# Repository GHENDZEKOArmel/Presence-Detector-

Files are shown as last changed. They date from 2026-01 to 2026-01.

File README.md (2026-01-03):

# Infrared Presence Detector – Electronic Design (KiCad)

##  Description
This project focuses on the design of an **active infrared presence detector** based on a
**fully analog signal processing chain**.

The system emits a modulated infrared signal, detects the reflection caused by a nearby object
(human presence), and processes the received signal in order to generate a **usable logic output**.

The project was designed and simulated using **KiCad**, with an **academic and educational purpose**,
following a modular architecture inspired by industrial detection systems.

---

##  Operating Principle

1. An **infrared emitting diode (IR LED)** generates a modulated IR signal.
2. A **photodiode receiver** detects the reflected infrared signal.
3. The received current is converted into a voltage (TIA).
4. A **band-pass filter** rejects ambient noise.
5. The signal is **amplified**.
6. A **peak detector** extracts the signal envelope.
7. A **comparator** compares the signal with an adjustable threshold.
8. A **logic output** indicates the detected presence.

### Functional blocks

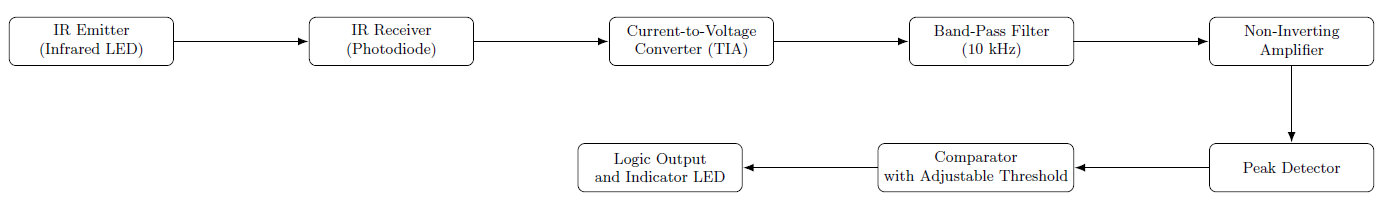
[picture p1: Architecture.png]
System architecture of the presence detector


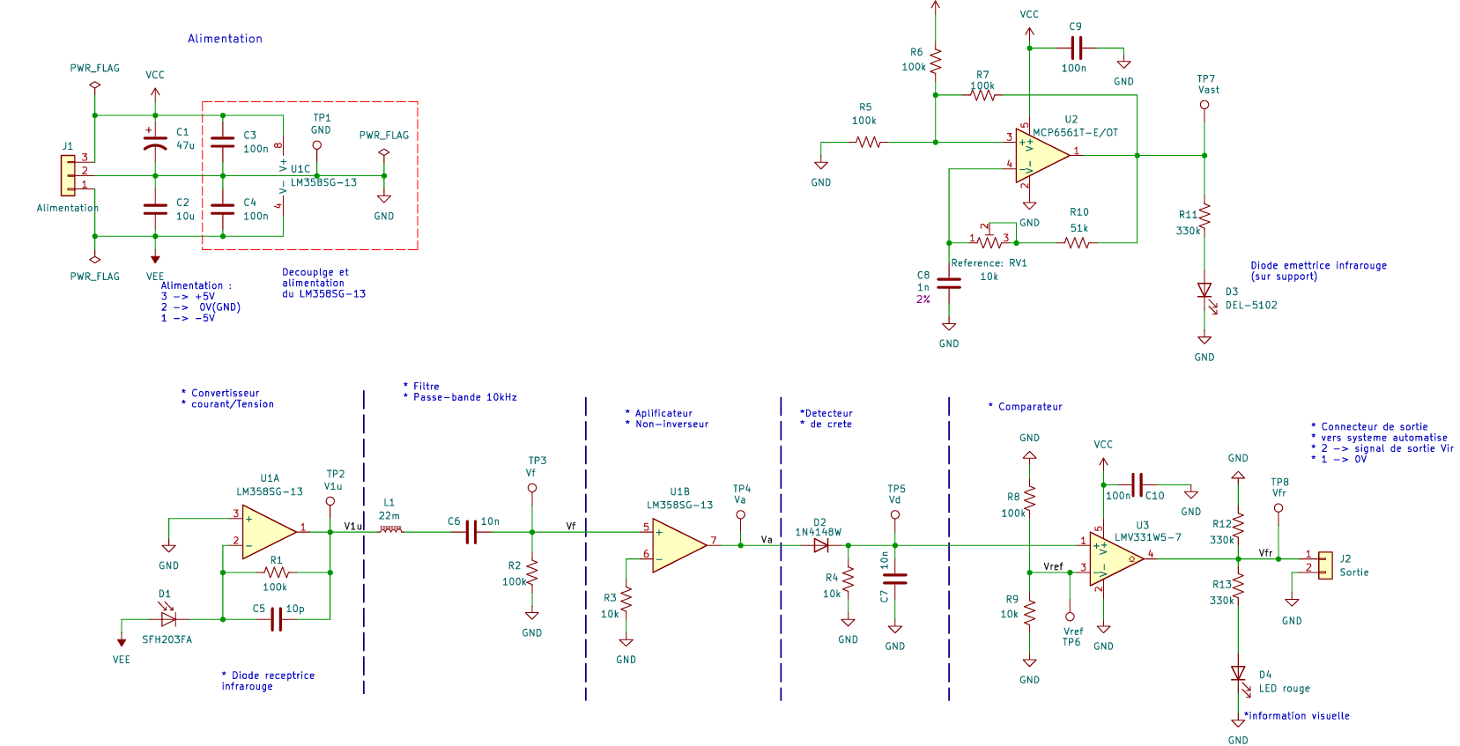
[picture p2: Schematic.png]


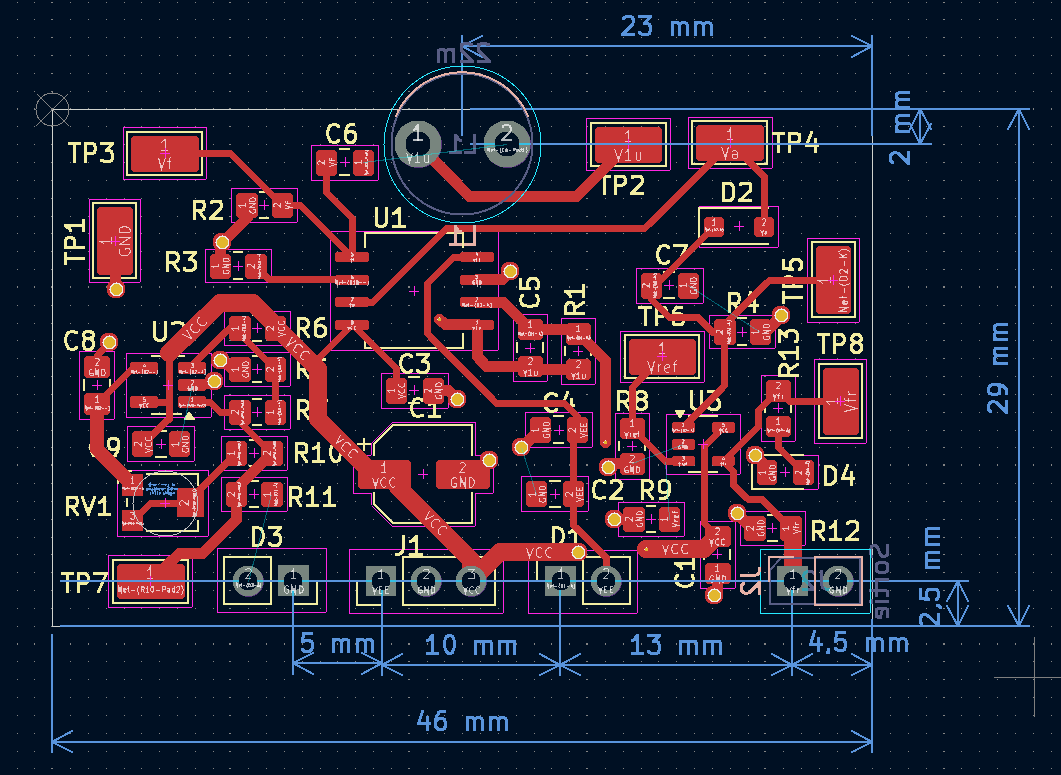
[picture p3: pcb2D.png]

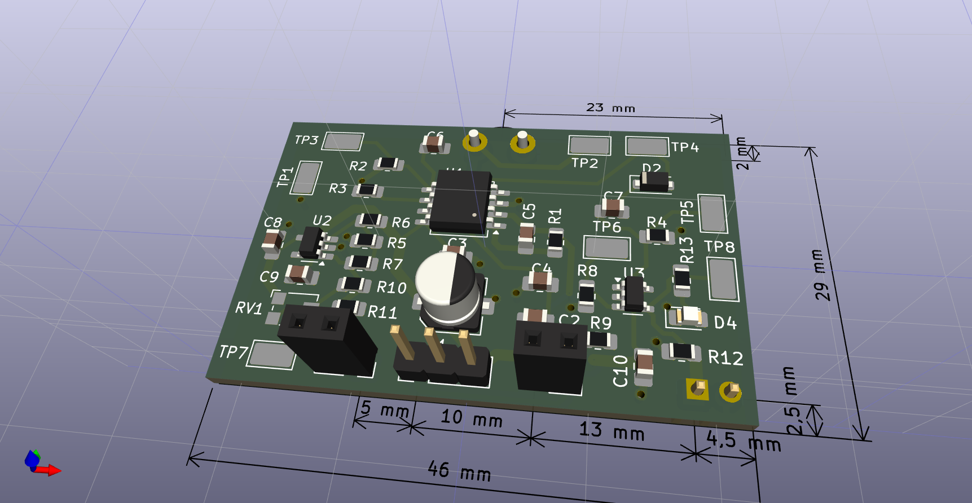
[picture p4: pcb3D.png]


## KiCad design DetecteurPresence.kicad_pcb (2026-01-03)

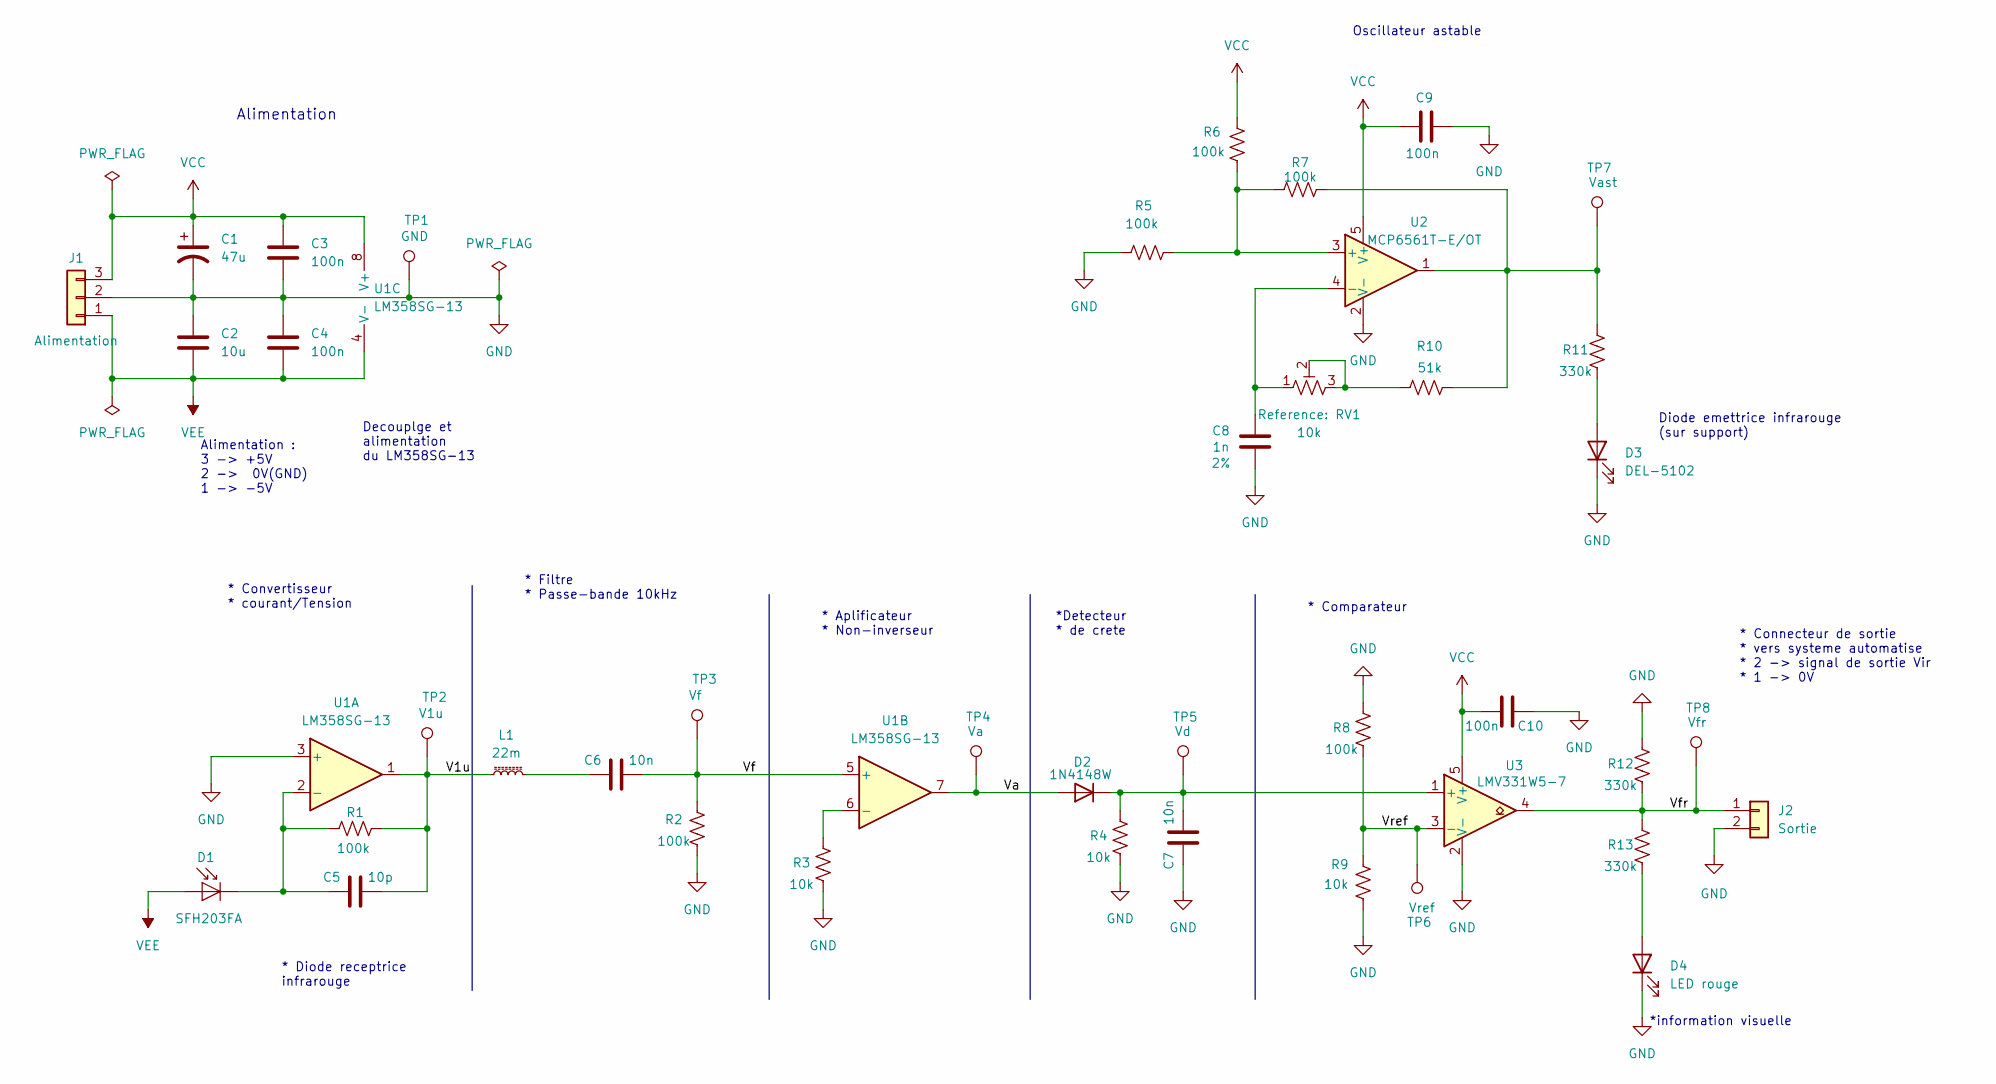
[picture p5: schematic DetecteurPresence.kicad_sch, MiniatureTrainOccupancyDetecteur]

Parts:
C1: 47u; CP_Elec_5x5.4
C2: 10u; C_0805_2012Metric_Pad1.18x1.45mm_HandSolder
C3, C4, C9, C10: 100n; C_0805_2012Metric_Pad1.18x1.45mm_HandSolder
C5: 10p; C_0805_2012Metric_Pad1.18x1.45mm_HandSolder
C6, C7: 10n; C_0805_2012Metric_Pad1.18x1.45mm_HandSolder
C8: 1n; C_0805_2012Metric_Pad1.18x1.45mm_HandSolder; Tolerance 2%
D1: SFH203FA; PinSocket_1x02_P2.54mm_Vertical
D2: 1N4148W; D_SOD-123F
D3: DEL-5102; PinSocket_1x02_P2.54mm_Vertical
D4: LED rouge; LED_0805_2012Metric_Pad1.15x1.40mm_HandSolder
J1: Alimentation; PinHeader_1x03_P2.54mm_Vertical
J2: Sortie; PinHeader_1x02_P2.54mm_Vertical
L1: 22m; L_Radial_D7.8mm_P5.00mm_Fastron_07HCP
R1, R2, R5, R6, R7, R8: 100k; R_0805_2012Metric_Pad1.20x1.40mm_HandSolder
R3, R4, R9: 10k; R_0805_2012Metric_Pad1.20x1.40mm_HandSolder
R10: 51k; R_0805_2012Metric_Pad1.20x1.40mm_HandSolder
R11, R12, R13: 330k; R_0805_2012Metric_Pad1.20x1.40mm_HandSolder
RV1: 10k; Potentiometer_Bourns_TC33X_Vertical
TP1: GND; TestPoint_Keystone_5019_Miniature
TP2: V1u; TestPoint_Keystone_5019_Miniature
TP3: Vf; TestPoint_Keystone_5019_Miniature
TP4: Va; TestPoint_Keystone_5019_Miniature
TP5: Vd; TestPoint_Keystone_5019_Miniature
TP6: Vref; TestPoint_Keystone_5019_Miniature
TP7: Vast; TestPoint_Keystone_5019_Miniature
TP8: Vfr; TestPoint_Keystone_5019_Miniature
U1: LM358SG-13; SOIC-8_5.3x6.2mm_P1.27mm
U2: MCP6561T-E/OT; SOT-23-5_HandSoldering
U3: LMV331W5-7; SOT-23-5

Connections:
/V1u: C5.2, L1.1, R1.2, TP2.1, U1.1
/Va: D2.2 (A), TP4.1, U1.7
/Vf: C6.2, R2.2, TP3.1, U1.5 (+)
/Vfr: J2.1, R12.1, R13.2, TP8.1, U3.4
/Vref: R8.1, R9.1, TP6.1, U3.3 (-)
GND: C1.2, C2.1, C3.2, C4.1, C7.1, C8.2, C9.1, C10.1, D3.1 (K), D4.1 (K), J1.2, J2.2, R2.1, R3.1, R4.1, R5.1, R8.2, R9.2, R12.2, TP1.1, U1.3 (+), U2.2 (V-), U3.2 (V-)
unnamed: C6.1, L1.2
unnamed: C5.1, D1.1 (K), R1.1, U1.2 (-)
unnamed: C7.2, D2.1 (K), R4.2, TP5.1, U3.1 (+)
unnamed: D3.2 (A), R11.1
unnamed: D4.2 (A), R13.1
unnamed: R10.1, RV1.2, RV1.3
unnamed: R7.2, R10.2, R11.2, TP7.1, U2.1
unnamed: R3.2, U1.6 (-)
unnamed: R5.2, R6.1, R7.1, U2.3 (+)
unnamed: C8.1, RV1.1, U2.4 (-)
VCC: C1.1, C3.1, C9.2, C10.2, J1.3, R6.2, U1.8 (V+), U2.5 (V+), U3.5 (V+)
VEE: C2.2, C4.2, D1.2 (A), J1.1, U1.4 (V-)

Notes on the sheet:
Alimentation
* Diode receptrice infrarouge
Decouplge et alimentation du LM358SG-13
*information visuelle
Diode emettrice infrarouge (sur support)
* Comparateur
*Detecteur * de crete
* Convertisseur * courant/Tension
Alimentation : 3 -> +5V 2 -> 0V(GND) 1 -> -5V
* Filtre * Passe-bande 10kHz
* Aplificateur * Non-inverseur
Oscillateur astable
* Connecteur de sortie * vers systeme automatise * 2 -> signal de sortie Vir * 1 -> 0V

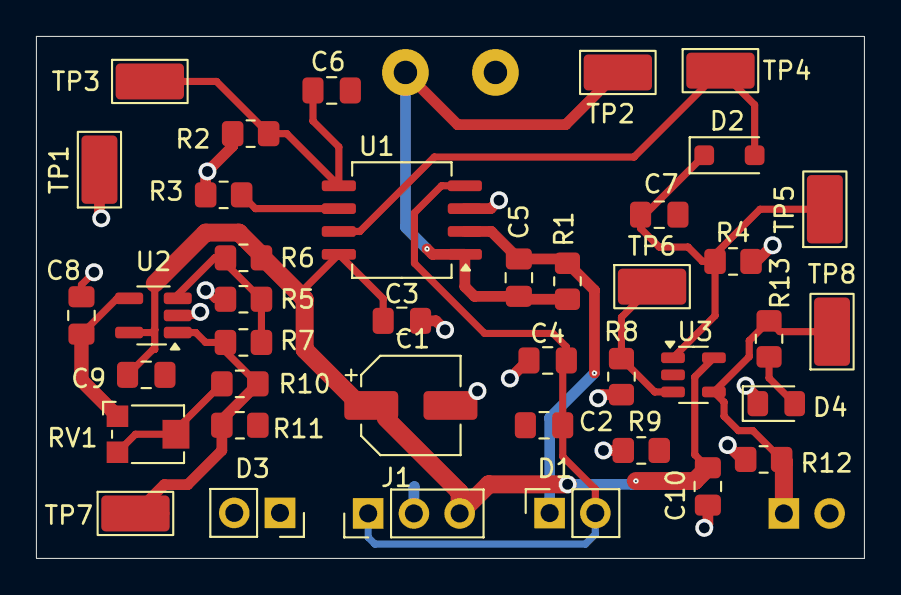
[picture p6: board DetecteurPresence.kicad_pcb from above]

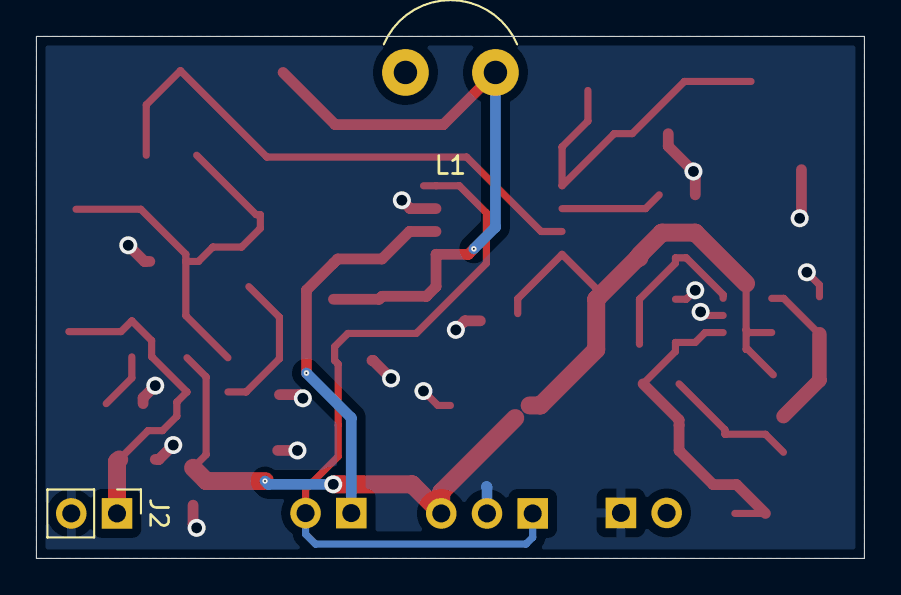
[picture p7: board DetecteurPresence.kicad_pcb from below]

Board: 2 copper layers, 46.0 x 29.0 mm, 42 parts (2 on the bottom side), 18 nets.
